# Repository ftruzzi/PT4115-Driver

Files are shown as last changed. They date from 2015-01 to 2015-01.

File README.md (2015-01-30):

PT4115 3-channel LED driver
===========================

Eagle files for my PT4115 3-channel (RGB) LED driver.

<p align="center">
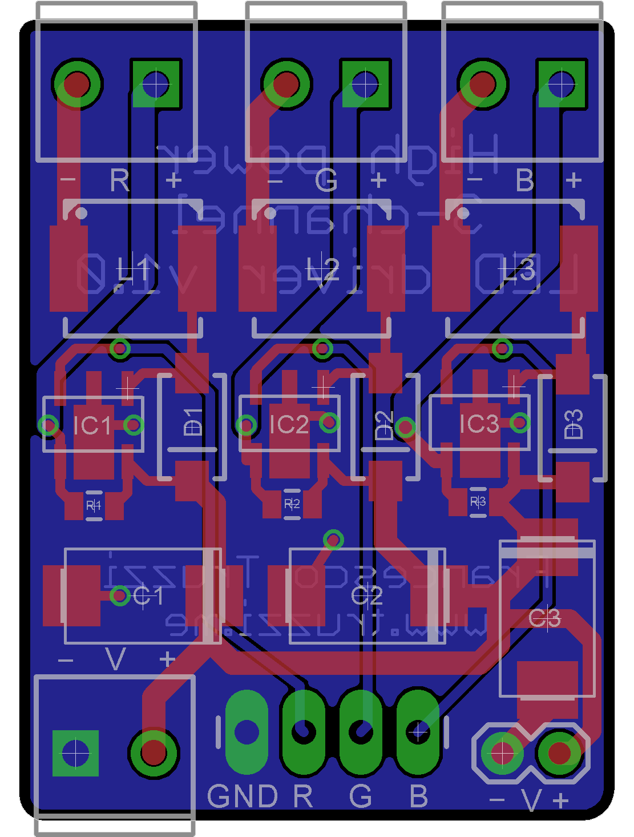
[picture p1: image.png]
  
</p>

##Features and parts list:

* **C1, C2, C3**: 22uF tantalum capacitors (DigiKey part number: 399-3781-1-ND)
* **D1, D2, D3**; Schottky diode 2A SMA package  (DigiKey part number: B240A-FDICT-ND)
* **L1, L2, L3**: 68uH power inductor, 0.7A (DigiKey part number: PCD2117CT-ND)
* **R1, R2, R3**: 0.33ohm resistors, 0805 package. These are current sense resistors. Current I=0.1/R (at maximum brightness).
* **4x screw terminals**: 3.5mm (bought mine on Tayda Electronics)
* **3x PT4115 drivers** (you can find them dirt cheap on eBay or Aliexpress)
* **1x 4-pin + 1x 2-pin** male or female headers.

Feel free to visit my website at http://truzzi.me.

Suggestions and feedback are very welcome!

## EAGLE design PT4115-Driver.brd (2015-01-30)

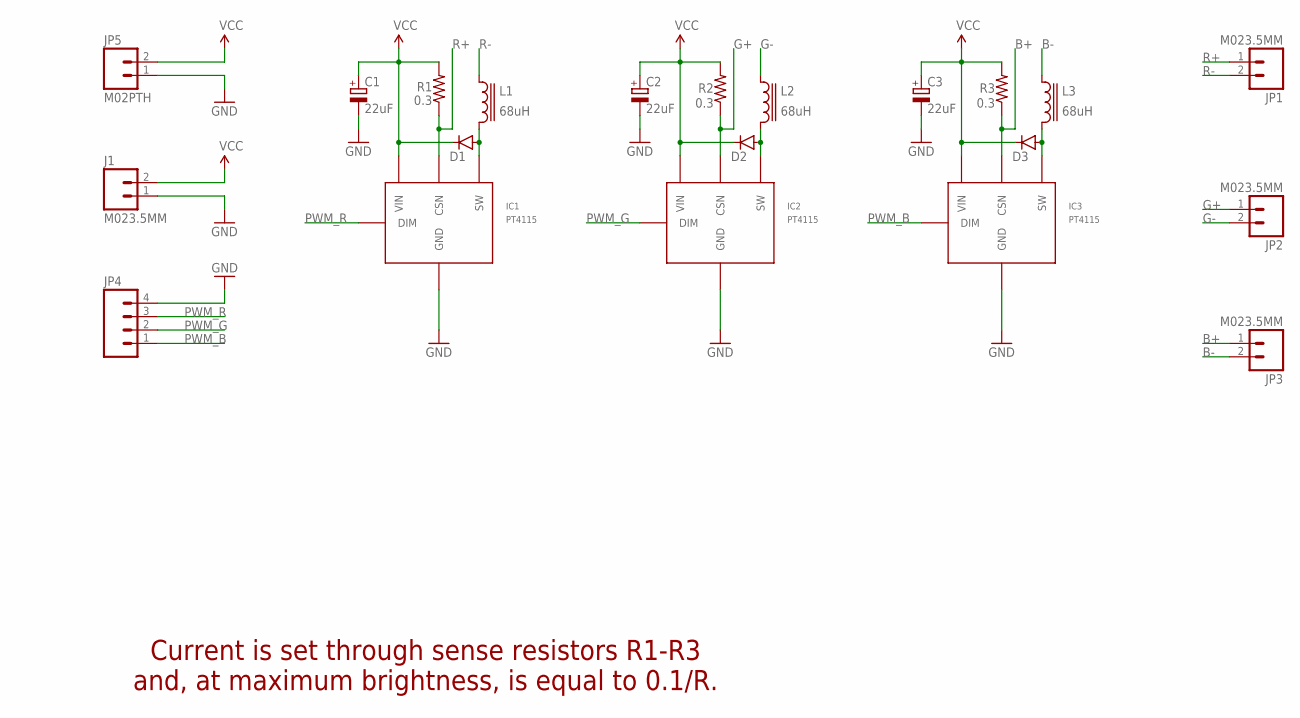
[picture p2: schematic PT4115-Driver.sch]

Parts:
C1, C2, C3: 22uF; D/7343-31R
D1, D2, D3: DIODESMA-KIT; SMA-DIODE-KIT
IC1, IC2, IC3: PT4115
J1: M023.5MM; SCREWTERMINAL-3.5MM-2
JP1, JP2, JP3: M023.5MM; SCREWTERMINAL-3.5MM-2
JP4: M04LONGPADS; 1X04_LONGPADS
JP5: M02PTH; 1X02
L1, L2, L3: 68uH; ELL6
R1, R2, R3: 0.3; 0805

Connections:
B+: IC3.4 (CSN), JP3.1, R3.1
B-: JP3.2, L3.1
G+: IC2.4 (CSN), JP2.1, R2.1
G-: JP2.2, L2.1
GND: C1.-, C2.-, C3.-, IC1.2 (GND), IC1.2A (GND), IC2.2 (GND), IC2.2A (GND), IC3.2 (GND), IC3.2A (GND), J1.1, JP4.4, JP5.1
unnamed: D1.A, IC1.1 (SW), L1.2
unnamed: D2.A, IC2.1 (SW), L2.2
unnamed: D3.A, IC3.1 (SW), L3.2
PWM_B: IC3.3 (DIM), JP4.1
PWM_G: IC2.3 (DIM), JP4.2
PWM_R: IC1.3 (DIM), JP4.3
R+: IC1.4 (CSN), JP1.1, R1.1
R-: JP1.2, L1.1
VCC: C1.+, C2.+, C3.+, D1.C, D2.C, D3.C, IC1.5 (VIN), IC2.5 (VIN), IC3.5 (VIN), J1.2, JP5.2, R1.2, R2.2, R3.2

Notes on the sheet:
Current is set through sense resistors R1-R3 and, at maximum brightness, is equal to 0.1/R.

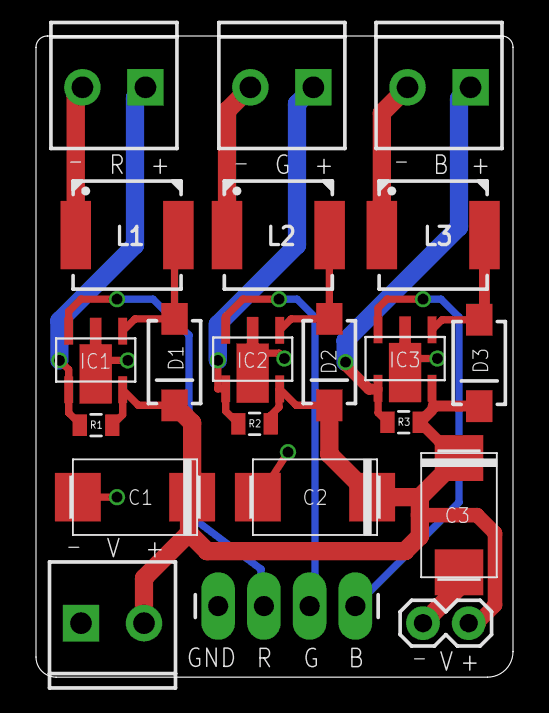
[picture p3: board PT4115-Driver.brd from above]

Board: 2 copper layers, 26.5 x 35.6 mm, 21 parts (0 on the bottom side), 14 nets.

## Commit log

2015-01-29 Eagle files for my PT4115 3-channel LED driver.
    [PT4115-Driver.brd, PT4115-Driver.sch]
2015-01-30 Improved schematics and board aesthetics
    [PT4115-Driver.brd, PT4115-Driver.sch]
2015-01-30 Fixed parts' values
    [PT4115-Driver.brd, PT4115-Driver.sch]

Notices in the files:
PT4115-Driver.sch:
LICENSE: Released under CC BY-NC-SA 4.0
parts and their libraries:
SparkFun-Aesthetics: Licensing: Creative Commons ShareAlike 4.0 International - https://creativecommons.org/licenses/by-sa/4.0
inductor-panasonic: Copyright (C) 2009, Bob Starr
